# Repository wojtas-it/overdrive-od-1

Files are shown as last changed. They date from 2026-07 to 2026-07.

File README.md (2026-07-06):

# OverDrive Unit OD-1

An analog guitar overdrive/distortion pedal built around a dual op-amp gain stage and diode clipping.

Schematic
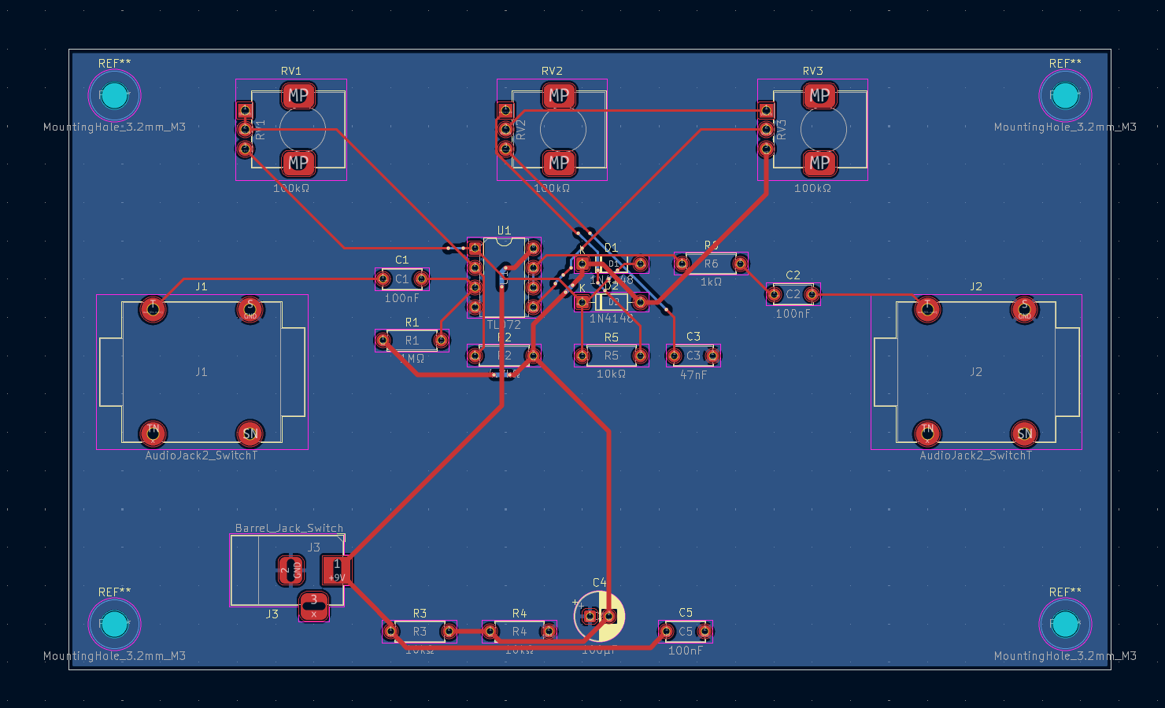
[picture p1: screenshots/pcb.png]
PCB layout


## Circuit overview

The signal path follows a classic op-amp overdrive topology, similar in spirit to circuits like the Tube Screamer: an op-amp gain stage feeding a diode clipper, followed by a passive tone filter and a buffered output stage.

- **Input stage** - high impedance input (1 MOhm), AC-coupled with a 100 nF capacitor so the pedal doesn't load down the guitar's pickups.
- **Gain stage** - one half of a TL072 op-amp, with the GAIN pot (100 kOhm) in the feedback path. Gain is adjustable roughly from unity up to around 100x.
- **Clipping stage** - two 1N4148 diodes wired anti-parallel to virtual ground, symmetrically clipping the signal at about +/-0.7 V. This is what generates the overdrive harmonics.
- **Tone stage** - a passive RC low-pass filter with a 100 kOhm TONE pot, shaping the signal from dark to bright.
- **Output stage** - the second half of the TL072 as a buffer/gain stage with the VOLUME pot (100 kOhm log), followed by an output coupling capacitor and a low output impedance (under 1 kOhm) so it can drive an amp or the next pedal in the chain.
- **Power** - runs from a single 9V supply (battery or DC adapter). A resistor divider plus a third TL072 buffer generates a virtual ground at 4.5 V so the op-amps can work single-supply. Current draw is under 10 mA.

Full details, block diagram, and the BOM are in [docs](docs).

Note: the docs were submitted as a two-person university assignment, so a partner's name appears on them alongside mine. In practice I designed and built this alone; the partner didn't contribute.

## Tools

- KiCad 9.0.5 for schematic capture and PCB layout
- Standard KiCad libraries only (Device, Amplifier_Operational, Diode, Connector, Connector_Audio, power) - no custom parts, so the project opens without missing library errors

## Status

- Schematic: complete, passes ERC with 0 errors and 0 warnings
- PCB layout: complete, 2-layer board, routed
- Physical build: not yet built, so there's no prototype photo yet
- Testing: not yet documented

The schematic and PCB layout above are exported from the KiCad files in [kicad](kicad). A photo of the physical pedal will be added here once it's built.

Designed in 2026 as a university electronics project.

## More

Portfolio: [wojtas.it](https://wojtas.it)

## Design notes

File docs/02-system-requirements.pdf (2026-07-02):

# WYMAGANIA SYSTEMOWE (Etap II)

Projektowanie Układów Elektronicznych II Urządzenie: OverDrive Unit OD-1
Filip Wojtasiński - 37747 | | | Tomasz Lesiak - 37708
Kategoria | Opis wymagania | Wartość / Specyfikacja
Napięcie zasilania | Urządzenie zasilane baterą lub zasilaczem sieciowym | 9V DC
Pobór prądu | Maksymalny pobór prądu podczas pracy | < 10 mA
Polaryzacja zasilania | Standardowe złącze zasilające | Wtyk DC 2,1 mm, masa na zewnątrz
Liczba wejść audio | Jedno wejście sygnału analogowego | 1 x jack 3,5 mm lub 6,35 mm
Liczba wyjść audio | Jedno wyjście sygnału analogowego | 1 x jack 3,5 mm lub 6,35 mm
Poziom sygnału wejściowego | Typowy poziom sygnału z gitary elektrycznej lub telefonu | 50 mV – 300 mV
Impedancja wejściowa | Wysoka impedancja - nie obciąża źródła sygnału | ≥ 1 MΩ
Impedancja wyjściowa | Niska impedancja - możliwość wysterowania kolejnych urządzeń | ≤ 1 kΩ
Pasmo przenoszenia | Zakres częstotliwości przetwarzanego sygnału audio | 20 Hz – 20 kHz
Zakres temperatur pracy | Temperatura otoczenia podczas normalnej eksploatacji | 0°C – 40°C
Regulacja przesterowania | Pokrętło GAIN — stopień zniekształcenia sygnału | Zakres ciągły: min – max
Regulacja barwy dźwięku | Pokrętło TONE — filtrowanie wysokich częstotliwości | Zakres ciągły: ciemny – jasny
Regulacja głośności | Pokrętło VOLUME — poziom sygnału wyjściowego | Zakres ciągły: 0 – max
Forma urządzenia i rozmiar | Prototyp realizowany na płytce stykowej (breadboard) | Breadboard standardowy
Wodoodporność | Ochrona przed zachlapaniem | IPX4
Pyłoszczelność | Częściowa ochrona przed pyłem | IP5X
Wymiary | Maksymalne wymiary obudowy | 120 x 70 x 50 mm

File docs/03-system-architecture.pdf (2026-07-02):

## ARCHITEKTURA SYSTEMU (Etap III)

Projektowanie Układów Elektronicznych II Urządzenie: OverDrive Unit OD-1

Filip Wojtasiński - 37747 | Tomasz Lesiak – 37708

## 1. Diagram blokowy systemu

Ponizej przedstawiono schemat blokowy urządzenia OverDrive Unit OD-1, pokazujący przepływ sygnału audio oraz główne bloki funkcjonalne

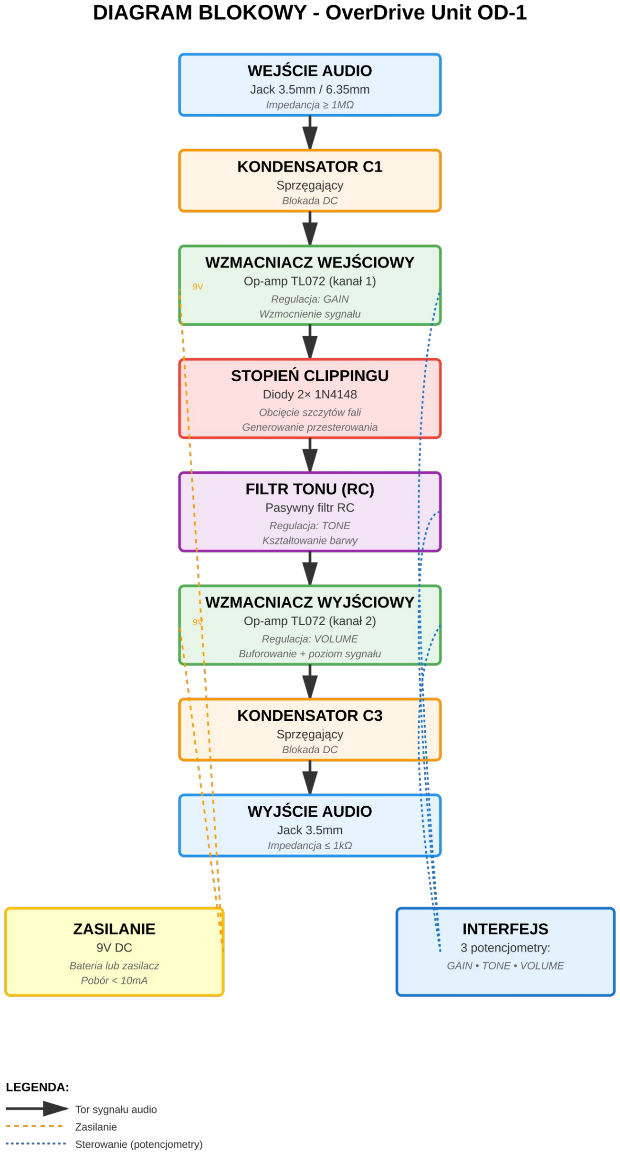
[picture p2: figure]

:

## 2. Opis bloków funkcjonalnych

### 2.1. Wejście audio

Rola: Punkt połączenia z zewnętrznym źródłem sygnału audio (gitara elektryczna, bas, telefon, odtwarzacz).
Specyfikacja: Złącze jack 3.5mm lub 6.35mm (standardowe złącze audio). Wysokoimpedancyjne wejście (≥1 MΩ) nie obciąża źródła sygnału, zachowując pełną charakterystykę dźwięku gitary.

### 2.2. Kondensator sprzęgający C1

Rola: Blokuje składową stałą napięcia (DC) z sygnału wejściowego, przepuszczając tylko składową zmienną (AC), czyli czysty sygnał audio.
Implementacja: Kondensator elektrolityczny lub ceramiczny o pojemności 100nF - 1µF. Współpracuje z impedancją wejściową wzmacniacza, tworząc filtr górnoprzepustowy z częstotliwością graniczną poniżej pasma audio.

### 2.3. Wzmacniacz wejściowy (Stopień wzmocnienia GAIN)

Rola: Wzmacnia słaby sygnał wejściowy z gitary (typowo 50-300 mV) do poziomu wystarczającego do efektywnego clippingu. Stopień wzmocnienia jest regulowany przez użytkownika za pomocą potencjometru GAIN.
Implementacja: Pierwszy kanał wzmacniacza operacyjnego TL072 w konfiguracji odwracającej lub nieodwracającej. Potencjometr GAIN (100kΩ, liniowy lub logarytmiczny) kontroluje wzmocnienie poprzez zmianę rezystancji w pętli sprzężenia zwrotnego.
Zakres wzmocnienia: Od ~1× (brak wzmocnienia, czysty sygnał) do ~100× (silne wzmocnienie, agresywny overdrive). Im wyższe wzmocnienie, tym bardziej intensywne przesterowanie.

### 2.4. Stopień clippingu (Generowanie przesterowania)

Rola: Celowe zniekształcenie sygnału audio poprzez obcięcie (clipping) szczytów fali. Generuje harmoniczne odpowiedzialne za charakterystyczne brzmienie overdrive/distortion.
Implementacja: Para diod krzemowych 1N4148 połączonych antyrównolegle (przeciwsobnie). Diody zaczynają przewodzić przy napięciu progowym ~0.7V, "ścinając" szczyty sygnału powyżej tego progu.
Efekt akustyczny: Sygnał sinusoidalny przekształca się w kształt zbliżony do fali prostokątnej, bogaty w harmoniczne nieparzyste i parzyste - charakterystyczne "ciepłe" brzmienie rockowe/metalowe.

### 2.5. Filtr tonu RC (Regulacja barwy dźwięku)

Rola: Kształtowanie barwy dźwięku poprzez tłumienie lub przepuszczanie określonych częstotliwości. Umożliwia dostosowanie charakteru brzmienia od ciemnego (mniej wysokich tonów) do jasnego (więcej wysokich tonów).
Implementacja: Pasywny filtr dolnoprzepustowy RC składający się z rezystora stałego i potencjometru TONE (10kΩ - 100kΩ, liniowy) połączonego z kondensatorem. Potencjometr zmienia częstotliwość graniczną filtru.
Efekt regulacji: Pozycja minimalna (TONE = 0) - ciemne, stłumione brzmienie z mniejszą ilością wysokich częstotliwości. Pozycja maksymalna (TONE = 100%) - jasne, ostre brzmienie z pełnym pasmem wysokich tonów.

### 2.6. Wzmacniacz wyjściowy (Stopień buforujący VOLUME)

Rola: Przywraca odpowiedni poziom sygnału wyjściowego oraz izoluje układ od obciążenia wyjściowego (kolejne urządzenia audio, wzmacniacz gitarowy). Regulacja głośności pozwala użytkownikowi dostosować poziom sygnału bez zmiany charakteru przesterowania. Implementacja: Drugi kanał wzmacniacza operacyjnego TL072. Może pracować jako wtórnik napięciowy (buffer, wzmocnienie 1×) lub wzmacniacz nieodwracający z potencjometrem VOLUME (100kΩ, logarytmiczny) kontrolującym wzmocnienie lub tłumienie.
Impedancja wyjściowa: Niska impedancja (≤1 kΩ) gwarantuje zdolność do sterowania następnych urządzeń w łańcuchu audio bez strat sygnału.

### 2.7. Kondensator sprzęgający C3

Rola: Podobnie jak C1 - blokuje składową stałą napięcia (DC) przed wyjściem, chroniąc kolejne urządzenia w łańcuchu audio przed uszkodzeniem. Przepuszcza tylko czysty sygnał AC. Implementacja: Kondensator elektrolityczny lub ceramiczny (100nF - 1µF). Razem z impedancją wejściową następnego urządzenia tworzy filtr górnoprzepustowy.

### 2.8. Wyjście audio

Rola: Punkt połączenia z następnym urządzeniem w łańcuchu audio (wzmacniacz gitarowy, interfejs audio, mikser, słuchawki).
Specyfikacja: Złącze jack 3.5mm (wersja prototypowa/uniwersalna) lub 6.35mm (wersja finalna dla gitarzystów). Niska impedancja wyjściowa (≤1 kΩ) zapewnia kompatybilność z większością urządzeń audio.

### 2.9. Zasilanie

Rola: Dostarcza energię elektryczną do wszystkich aktywnych elementów układu (wzmacniaczy operacyjnych TL072).
Źródło zasilania: Bateria 9V (standardowa 6F22) lub zasilacz sieciowy 9V DC z wtykiem DC 2.1mm (masa na zewnątrz, zgodnie ze standardem pedałów gitarowych).
Pobór prądu: Mniej niż 10 mA (TL072 to energooszczędny układ JFET). Bateria 9V o pojemności ~500 mAh zapewnia ~50 godzin pracy.
Virtual Ground: Dzielnik napięcia (2× rezystor 10kΩ + kondensator 100µF) tworzy "sztuczną masę" (Virtual Ground) na poziomie 4.5V, umożliwiając pracę wzmacniaczy operacyjnych w konfiguracji single-supply (zasilanie z jednego źródła).

### 2.10. Interfejs użytkownika

Rola: Umożliwia użytkownikowi kontrolę nad trzema kluczowymi parametrami brzmienia urządzenia. Elementy sterujące:
- GAIN (potencjometr 100kΩ) - regulacja stopnia wzmocnienia i intensywności przesterowania
- TONE (potencjometr 10-100kΩ) - regulacja barwy dźwięku (ciemny ↔ jasny)
- VOLUME (potencjometr 100kΩ, logarytmiczny) - regulacja poziomu głośności sygnału wyjściowego

## 3. Przepływ sygnału

System realizuje przetwarzanie sygnału audio w następującej sekwencji:

1. Sygnał audio z gitary (typowo 50-300 mV, impedancja ~10-50 kΩ) wchodzi przez wejście audio (jack).

### 2. Kondensator sprzęgający C1 usuwa składową DC z sygnału, przepuszczając tylko składową

zmienną AC (sygnał audio).

### 3. Sygnał trafia do wzmacniacza wejściowego (TL072), gdzie jest wzmacniany zgodnie z

ustawieniem potencjometru GAIN (zakres wzmocnienia 1×–100×).
4. Wzmocniony sygnał (nawet do kilku woltów) przechodzi przez stopień clippingu (diody 1N4148), gdzie szczyty fali przekraczające ±0.7V są obcinane, generując przesterowanie i harmoniczne.
5. Zniekształcony sygnał przechodzi przez filtr tonu (RC), gdzie użytkownik reguluje barwę za pomocą potencjometru TONE - od ciemnego, stłumionego brzmienia do jasnego, agresywnego.
6. Sygnał trafia do wzmacniacza wyjściowego (TL072), gdzie poziom głośności jest regulowany potencjometrem VOLUME. Wzmacniacz działa też jako bufor izolujący układ od obciążenia.
7. Kondensator sprzęgający C3 ponownie blokuje składową DC przed wyjściem, chroniąc kolejne urządzenia.
8. Przetworzony sygnał audio (poziom linii, niska impedancja) wychodzi przez wyjście audio (jack) do wzmacniacza gitarowego, interfejsu audio lub słuchawek.

Równolegle do toru sygnałowego, blok zasilania 9V DC dostarcza energię do obu kanałów wzmacniacza operacyjnego TL072. Dzielnik napięcia generuje Virtual Ground (4.5V), który stanowi punkt odniesienia dla całego układu w konfiguracji single-supply.

## 4. Podsumowanie

Architektura OverDrive Unit OD-1 opiera się na klasycznym analogowym torze przetwarzania sygnału audio, zoptymalizowanym pod kątem prostoty konstrukcji, niezawodności i wysokiej jakości dźwięku. System składa się z trzech głównych grup bloków funkcjonalnych:

Tor sygnałowy (8 bloków): wejście audio → kondensator C1 → wzmacniacz wejściowy (GAIN) → stopień clippingu (diody) → filtr tonu (TONE) → wzmacniacz wyjściowy (VOLUME) → kondensator C3 → wyjście audio. Każdy blok pełni określoną rolę w procesie kształtowania charakterystycznego brzmienia overdrive/distortion.
Zasilanie: blok zasilania 9V DC (bateria lub zasilacz) z Virtual Ground zapewnia energię dla aktywnych elementów układu (wzmacniaczy operacyjnych). Energooszczędna konstrukcja (pobór <10 mA) gwarantuje długą pracę z baterii.
Interfejs użytkownika: trzy potencjometry (GAIN, TONE, VOLUME) umożliwiają pełną kontrolę nad charakterem brzmienia w czasie rzeczywistym. Użytkownik może płynnie regulować intensywność przesterowania, barwę dźwięku i głośność bez potrzeby przestawiania przełączników.

Układ realizuje przetwarzanie sygnału w czasie rzeczywistym, bez opóźnień (latency), co jest kluczowe dla komfortu gry na żywo. Analogowa natura układu zapewnia charakterystyczne, "ciepłe" brzmienie cenione przez gitarzystów.

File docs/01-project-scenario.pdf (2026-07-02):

## SCENARIUSZ PROJEKTU

Projektowanie Układów Elektronicznych II
Filip Wojtasiński - 37747 | | | Tomasz Lesiak - 37708
Nazwa urządzenia | OverDrive Unit OD-1
Typ urządzenia | Analogowy efekt gitarowy - Overdrive/Distortion
Docelowy użytkownik | Gitarzysta, muzyk, producent muzyczny
Zasilanie | 9V DC (bateria lub zasilacz sieciowy)
Interfejs | Wejście / wyjście jack 3,5 mm lub 6,35 mm

### 1. Kontekst i zlecenie

Firma zleca opracowanie prostego, analogowego efektu gitarowego typu Overdrive/Distortion przeznaczonego dla muzyków i producentów muzycznych. Urządzenie ma być niedrogie w produkcji, niezawodne i łatwe w obsłudze - dobre zarówno dla początkujących gitarzystów, jak i do zastosowań w domowym studiu nagrań.

### 2. Problem do rozwiązania

Profesjonalne pedały gitarowe z efektem przesterowania dostępne na rynku kosztują nawet do kilkuset złotych, co stanowi barierę dla początkujących muzyków. Istnieje zapotrzebowanie na proste, tanie i niezawodne rozwiązanie, które pozwoli uzyskać charakterystyczne brzmienie rockowe i metalowe bez inwestowania w drogi sprzęt.
Dodatkowo, popularne rozwiązania cyfrowe (procesory efektów) wprowadzają opóźnienia sygnału niepożądane podczas gry na żywo. Analogowy układ elektroniczny eliminuje ten problem -przetwarzanie sygnału odbywa się w czasie rzeczywistym, bez żadnych opóźnień. Ponadto niektórzy użytkownicy cenią sobie analogowe brzmienia, określając je jako bardziej klasyczne.

### 3. Opis urządzenia

### 3.1. Zasada działania

Urządzenie przetwarza analogowy sygnał audio z gitary elektrycznej lub innego źródła dźwięku. Sygnał jest wzmacniany przez wzmacniacz operacyjny, a następnie poddawany celowemu zniekształceniu poprzez diody clippingowe, które obcinają szczyty fali sinusoidalnej. Efektem jest charakterystyczne przesterowanie bogate w harmoniczne, typowe dla brzmienia rockowego i metalowego.

### 3.2. Główne funkcje urządzenia

- Wzmocnienie i zniekształcenie sygnału audio w czasie rzeczywistym
- Regulacja stopnia przesterowania - pokrętło GAIN
- Regulacja barwy dźwięku - pokrętło TONE
- Regulacja głośności sygnału wyjściowego - pokrętło VOLUME
- Kompatybilność z gitarą elektryczną, basem oraz innymi źródłami audio (np. telefon)

### 3.3. Bloki funkcjonalne układu

- Wzmacniacz wejściowy - wzmocnienie słabego sygnału wejściowego
- Stopień clippingu - zniekształcenie sygnału, generowanie harmonicznych
- Filtr tonu (pasywny filtr RC) - kształtowanie barwy dźwięku
- Wzmacniacz wyjściowy - dostosowanie poziomu sygnału wyjściowego

### 4. Docelowy użytkownik

Urządzenie kierowane jest do gitarzystów elektrycznych i basistów na każdym poziomie zaawansowania, a także do producentów muzycznych pracujących w domowym studiu. Użytkownik nie musi posiadać wiedzy technicznej - obsługa sprowadza się do podłączenia kabli i regulacji trzech pokręteł.

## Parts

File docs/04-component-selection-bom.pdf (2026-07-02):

## DOBÓR KOMPONENTÓW I BOM (Etap IV)

Projektowanie Układów Elektronicznych II OverDrive Unit OD-1

Filip Wojtasiński - 37747 | Tomasz Lesiak - 37708

### 1. Dobór komponentów

Układ scalony: TL072CP - podwójny wzmacniacz operacyjny JFET w obudowie DIP-8. Dobrano ze względu na niski szum (low-noise), szerokie pasmo przenoszenia (3 MHz), niski pobór prądu (~2.8 mA) oraz powszechną dostępność. Klasyczny wybór do aplikacji audio, szczególnie w efektach gitarowych.
Diody clippingowe: 1N4148 - krzemowe diody szybkie w obudowie DO-35. Napięcie przewodzenia ~0.7V zapewnia symetryczne obcinanie sygnału. Standardowy wybór w klasycznych pedałach overdrive (Tube Screamer, DOD 250). Tanie, łatwo dostępne.
Rezystory: Rezystory węglowe lub metalowo-warstwowe THT, tolerancja 5%, moc 0.25W. Wartości dobrano zgodnie z wymaganymi parametrami wzmocnienia, impedancji wejściowej/wyjściowej oraz częstotliwości granicznych filtrów. Potencjometry: 100 kΩ w obudowie PCB mount lub z przewodami. GAIN i TONE -liniowe (typ B) dla równomiernej regulacji. VOLUME - logarytmiczny (typ A) dla naturalnej percepcji głośności przez użytkownika.
Kondensatory: C1, C2 (100 nF ceramiczne) - sprzęgające, blokują DC. C3 (47 nF) -część filtru tonu RC. C4 (100 µF elektrolityczny) - wygładzanie Virtual Ground. C5 (100 nF) - odsprzęganie zasilania op-ampa, eliminuje szumy i oscylacje.
Złącza: Jack 6.35 mm (1/4") mono THT - standard w sprzęcie gitarowym. Gniazdo DC 2.1 mm center negative - zgodne ze standardem pedałów 9V.
Dostępność: Wszystkie komponenty powszechnie dostępne w sklepach elektronicznych (TME, Botland, Kamami). Obudowy THT umożliwiają łatwy montaż na breadboardzie.

### 2. Lista materiałowa (BOM)

Oznaczenie | Nazwa / Typ | Wartość / Parametry | Obudowa | Ilość
U1 | TL072CP | Dual Op-Amp JFET, low-noise | DIP-8 | 1
D1, D2 | 1N4148 | Dioda krzemowa szybka, 0.7V | DO-35 | 2
R1 | Rezystor | 1 MΩ, 0.25W, 5% | THT | 1
R2 | Rezystor | 4.7 kΩ, 0.25W, 5% | THT | 1
R3, R4, R5 | Rezystor | 10 kΩ, 0.25W, 5% | THT | 3
R6 | Rezystor | 1 kΩ, 0.25W, 5% | THT | 1
POT1 | Potencjometr GAIN | 100 kΩ, liniowy (B) | PCB/Wire | 1
POT2 | Potencjometr TONE | 100 kΩ, liniowy (B) | PCB/Wire | 1
POT3 | Potencjometr VOLUME | 100 kΩ, logarytmiczny (A) | PCB/Wire | 1
C1, C2, C5 | Kondensator ceramiczny | 100 nF, 50V | THT | 3
C3 | Kondensator ceramiczny | 47 nF, 50V | THT | 1
C4 | Kondensator elektrolityczny | 100 µF, 16V | THT | 1
J1, J2 | Gniazdo jack 6.35mm | Mono, THT (wejście/wyjści e) | THT | 2
J3 | Gniazdo DC 2.1mm | 9V, center negative | THT | 1
- | Breadboard | 830 punktów stykowych | - 1
- Przewody | połączeniowe | Zestaw do breadboard | - ~20
- | Zasilanie | Bateria 9V (6F22) lub zasilacz 9V DC | - 1

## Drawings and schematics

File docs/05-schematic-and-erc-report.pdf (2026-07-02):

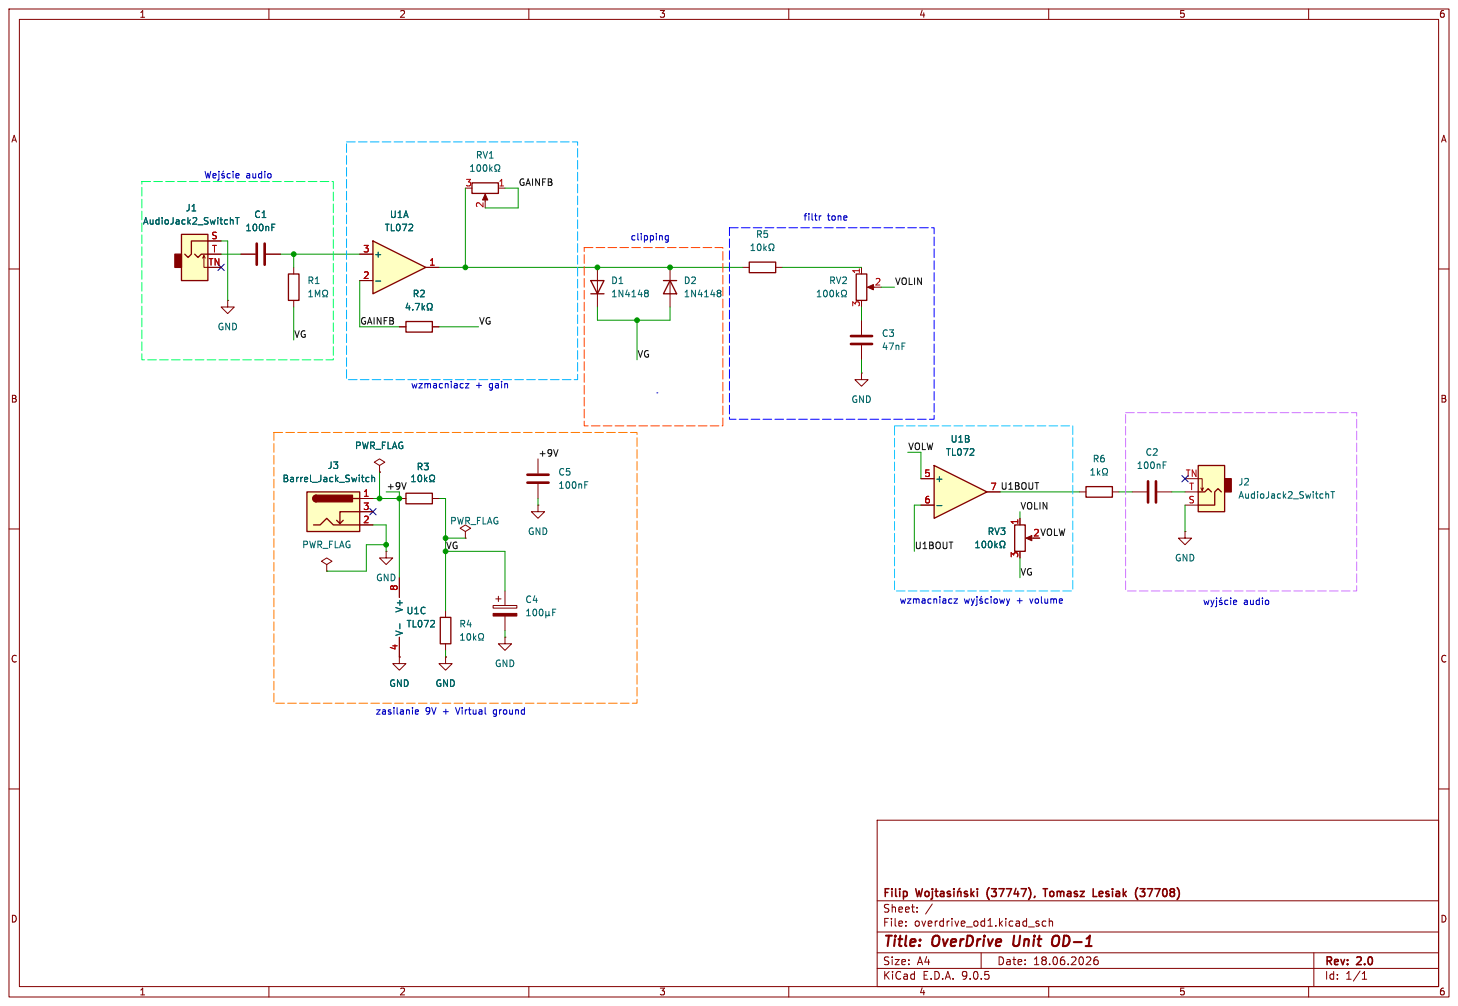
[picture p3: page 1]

Id: 1/1 Title: OverDrive Unit OD-1

# Raport kontroli reguł elektrycznych (ERC)

# OverDrive Unit OD-1 | Rev: 2.0 | Projektowanie Układów Elektronicznych II Filip Wojtasiński (37747), Tomasz Lesiak (37708) Narzędzie: KiCad E.D.A. 9.0.5

# Treść raportu ERC

## Raport ERC (2026-06-21T20:47:02+0200, Kodowanie UTF8) ***** Arkusz / ** Liczba wiadomości ERC: 0 Błędów 0 Ostrzeżeń 0

# Wynik: 0 naruszeń (0 błędów, 0 ostrzeżeń)

Projekt przeszedł kontrolę poprawności elektrycznej (ERC) pomyślnie. Wszystkie połączenia są kompletne; brak błędów i ostrzeżeń.

Strona 2/2 — Raport ERC. Strona 1 zawiera kompletny schemat elektroniczny.

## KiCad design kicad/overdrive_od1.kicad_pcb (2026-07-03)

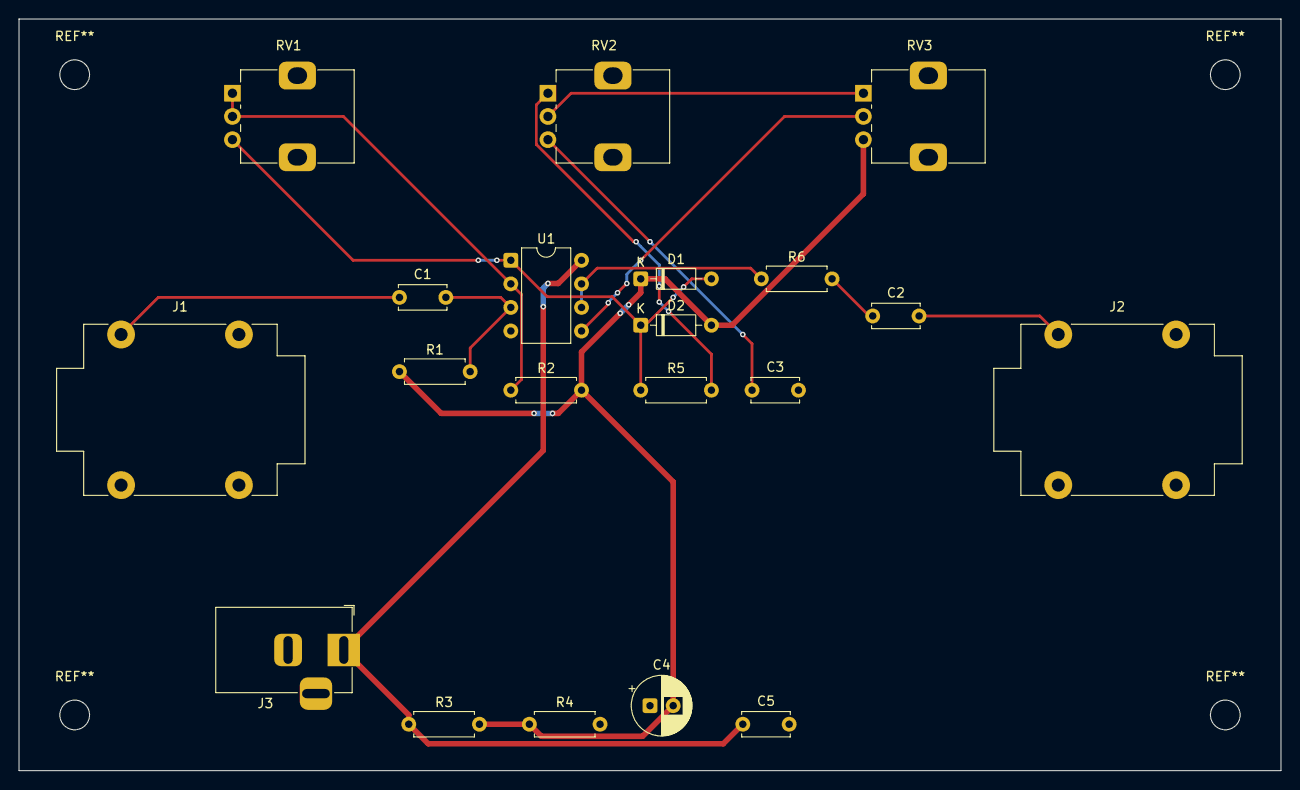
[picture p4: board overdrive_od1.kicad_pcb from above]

Board: 2 copper layers, 136.0 x 81.0 mm, 20 parts (0 on the bottom side), 14 nets.

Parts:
C1, C2, C5: 100nF; C_Disc_D5.0mm_W2.5mm_P5.00mm
C3: 47nF; C_Disc_D5.0mm_W2.5mm_P5.00mm
C4: 100µF; CP_Radial_D6.3mm_P2.50mm
D1, D2: 1N4148; D_DO-35_SOD27_P7.62mm_Horizontal
J1, J2: AudioJack2_SwitchT; Jack_6.35mm_Neutrik_NMJ4HCD2_Horizontal
J3: Barrel_Jack_Switch; BarrelJack_Horizontal
R1: 1MΩ; R_Axial_DIN0207_L6.3mm_D2.5mm_P7.62mm_Horizontal
R2: 4.7kΩ; R_Axial_DIN0207_L6.3mm_D2.5mm_P7.62mm_Horizontal
R3, R4, R5: 10kΩ; R_Axial_DIN0207_L6.3mm_D2.5mm_P7.62mm_Horizontal
R6: 1kΩ; R_Axial_DIN0207_L6.3mm_D2.5mm_P7.62mm_Horizontal
RV1, RV2, RV3: 100kΩ; Potentiometer_Alps_RK09K_Single_Vertical
U1: TL072; DIP-8_W7.62mm

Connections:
/+9V: C5.1, J3.1, R3.1, U1.8 (V+)
/GAINFB: R2.1, RV1.1, RV1.2, U1.2 (-)
/U1BOUT: R6.1, U1.6 (-), U1.7
/VG: C4.2, D1.1 (K), D2.2 (A), R1.1, R2.2, R3.2, R4.1, RV3.3
/VOLIN: RV2.2, RV3.1
/VOLW: RV3.2, U1.5 (+)
GND: C3.2, C4.1, C5.2, J1.S, J2.S, J3.2, R4.2, U1.4 (V-)
unnamed: C1.1, J1.T
unnamed: C2.1, R6.2
unnamed: C2.2, J2.T
unnamed: C3.1, RV2.3
unnamed: D1.2 (A), D2.1 (K), R5.1, RV1.3, U1.1
unnamed: R5.2, RV2.1
unnamed: C1.2, R1.2, U1.3 (+)

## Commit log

2026-07-02 Initial commit: OverDrive Unit OD-1 KiCad project and design docs
    Analog guitar overdrive pedal designed in KiCad 9. Includes schematic,
    routed 2-layer PCB, and the university project documentation (system
    requirements, architecture, BOM, ERC report).
    [overdrive_od1.kicad_pcb, overdrive_od1.kicad_sch]
2026-07-02 Add generated schematic, PCB layout, and 3D render screenshots
    Exported directly from the KiCad project with kicad-cli so the
    images always match the actual design files.
2026-07-03 Fix pcb-layout.svg being zoomed out to the full A4 page
    Cropped the viewBox to the board area so traces are actually visible
    instead of being tiny lines lost on a mostly-blank page.
2026-07-03 Add matching title block to PCB
    The PCB title block was empty; the schematic's title/date/rev/company
    weren't copied over automatically since KiCad keeps a separate title
    block per editor. Filled it in to match.
    [overdrive_od1.kicad_pcb]
2026-07-03 Drop the 3D PCB render from the README
    Several footprints (the pots and the audio jacks) have no 3D model
    shipped with this KiCad install, so the render shows them as blank
    gaps. The 2D layout and schematic already show the full board, so
    dropping the misleading render.
2026-07-03 Show only F.Cu in the PCB layout screenshot
    B.Cu is almost entirely a GND pour, so including it just renders the
    whole board as a solid fill and hides the actual traces. Re-exported
    with F.Cu, F.SilkS, and Edge.Cuts only, and noted why in the README.
2026-07-03 Replace generated PCB layout SVG with a manual KiCad screenshot
    The manual screenshot shows the full board clearly with labels and
    values, and doesn't have the GND pour hiding the traces the way the
    kicad-cli SVG export did.
